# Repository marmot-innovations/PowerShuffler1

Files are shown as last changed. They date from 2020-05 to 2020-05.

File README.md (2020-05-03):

# PowerShuffler1
Summary: PowerShuffler1 is a HV isolated DC-DC charger PCBA for balancing weak cells within a large battery stack of Li-Ion cells.

Theory of operation: In a battery stack with 99 lithium-ion cells in series, there might be 1 or 2 weak cells that limit the usability of the entire battery pack. Let's assume the 99 li-ion cells are arranged in groups of 9 and there are certain groups that contain cells which are stronger than others. PowerShuffler1 is a PCBA that will piggy-back on top of the existing BMS that comes with the battery pack and draw power from the stronger group in order to charge up the 1 weak cell wherever it sits in the series of 99 cells. PowerShuffler1 has built-in intelligence not to over-discharge the stronger group by measuring the voltage of the 1 weak cell as it rises, and compares it to 1/9th of the stronger group's total voltage as it falls to within a certain threshold. Pre-programmed hysteresis prevents excessive start-stop charging as the cells are put through normal usage during the time when the existing BMS kicks in. Although intrusive, PowerShuffler1 is meant to be a diagnostics tool to verify and characterize weak cells within a battery stack on top of a pre-existing BMS. It does not replace the need for servicing the battery pack or using a better BMS down the road. PowerShuffler1 has no wired or wireless communication, which is not accessible anyway if piggy-backed within a battery pack enclosure.

Included in this project are:
1. Firmware for master MCU
2. Firmware for client MCU
3. PCB design for PCBA

Read the individual README for further details. Pictures will be added later to provide instructions for programming and installation, as well as board modifications where needed. Test data will be provided eventually.

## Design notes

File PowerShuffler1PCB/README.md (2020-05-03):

## PowerShuffler 1.0 PCB design schematic, layout, Gerbers, and BOM  
KiCAD 5.0.0 for PCB design  
Microsoft Excel web for BOM  
No 3D model  
No XY pick and place Centroid  
No ODB++  
No footprint library  
No schematic library

Design bugs and comments:  
1. S2 pins 3 and 4 are swapped. Use wire wrap to un-swap them.
2. F2 will drop about 0.1V under full 500mA load when charging. No way to measure OCV in this version. Manually take measurements and compensate by adjusting master MCU.
3. R12 cannot be switched off to stop charging. Everytime the client MCU is turned on to take a measurement it will move energy.
4. To program master MCU, remove R6 and C7 first, then replace them once programming is completed. These components will put too much load on ISP TPI programmer.
5. To program client MCU, remove C24 and (optionally) R22 first, then replace them once completed. These components will put too much load on ISP TPI programmer.
6. J2 and J4 do not need soldered headers for programming. Just shove a 5-pin 0.1" straight strip header into it to establish electrical contact. Look up "sneaky footprints PCB" on the web.
7. Mounting holes are for 4-40 screws and stand-offs.
8. Peak 75% efficiency during max charge rate as measured.
9. Less than 0.5mA current draw from input when idle, not charging.

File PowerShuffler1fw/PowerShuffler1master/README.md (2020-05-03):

## PowerShuffler Master Firmware  
Microchip (Atmel) ATTINY10 8MHZ  
Operational VCC 3.3V  
Programming VCC 5.0V  
Reset line voltage 12V  
TPI programming interface  
Programmer AVR ISP mk2

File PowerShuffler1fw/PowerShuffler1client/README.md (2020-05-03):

## PowerShuffler Client Firmware  
Microchip (Atmel) ATTINY10 8MHZ  
Operational VCC 3.3V  
Programming VCC 5.0V  
Normal reset line voltage (no need for 12V)  
TPI programming interface  
Programmer AVR ISP mk2

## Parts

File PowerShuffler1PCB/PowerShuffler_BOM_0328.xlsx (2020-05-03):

ref | QTY | value5 | footprint | Manuf P/N | Digikey P/N | description
U2, U6 | 2 | SWITCHDCDCLOPOW | BMB:10-μMAX_3x3mm | MAX17550AUB+ | MAX17550AUB+-ND | IC REG BUCK ADJ 25MA 10UMAX
C26, C27 | 2 | 15u | BMB:2917 | TR3E156M050C0300‎ | 718-1785-1-ND‎ | CAP TANT 15UF 20% 50V 2917
J3 | 1 | Conn_01x02 | BMB:Molex_Microfit3_Header_2pin_Angled_43650 | 0436500200‎ | WM1860-ND | CONN HEADER R/A 2POS 3MM
J1 | 1 | Conn_01x03 | BMB:Molex_Microfit3_Header_3pin_Angled_43650 | 0436500301‎ | ‎WM1866-ND‎ | CONN HEADER R/A 3POS 3MM
U4 | 1 | ISOLATEDDCDC | BMB:NSD05-S_6-DIP_1x1.6inch | NSD05-48S5‎ | 1866-3621-ND‎ | DC DC CONVERTER 5V 5W isolated
L1, L2 | 2 | 680u | BMB:SMD_Inductor_Shielded_6x6mm | VLS6045EX-681M | ‎445-180928-1-ND | FIX IND 680UH 320MA 2.95OHM SMD
S1 | 1 | SSR4 | BMB:SMD4_SSR_CPC1002N | CPC1002NTR‎ | CLA230CT-ND | SSR RELAY SPST-NO 700MA 0-60V
S2 | 1 | OPTOSOLO | BMB:SMD4_TL241AF-SSR_0.1_12x5mm | ‎LTV-816S | ‎160-1361-5-ND | OPTOISOLATR 5KV TRANSISTOR 4-SMD
J2 | 1 | Conn_01x05 | BMB:Staggered_ICSP_5x2.54mm_Straight |  |  | DO NOT POPULATE
J4 | 1 | Conn_01x05 | BMB:Staggered_ICSP_5x2.54mm_Straight |  |  | DO NOT POPULATE
C12, C14, C16, C19, C2, C28, C6, C9 | 8 | 0.1u | Capacitors_SMD:C_1206 | CL31B104KCFNNNE‎ | 1276-1151-1-ND | CAP CER 0.1UF 100V X7R 1206
C10, C22 | 2 | 0.22u | Capacitors_SMD:C_1206 | CL31B224KBFNNNE‎ | 1276-1106-1-ND
C20, C25, C4 | 3 | 10u | Capacitors_SMD:C_1206 | CL31B106KBHNNNE‎ | 1276-6767-1-ND | CAP CER 10UF 50V X7R 1206
C1, C11, C13, C15, C18, C21, C24, C3, C5, C7, C8 | 11 | 1u | Capacitors_SMD:C_1206 | CL31B105KBHNNNE‎ | ‎1276-1068-1-ND‎ | CAP CER 1UF 50V X7R 1206
C17, C23 | 2 | 4.7u | Capacitors_SMD:C_1206 | CL31B475KAHNNWE‎ | ‎1276-3178-1-ND
F1 | 1 | Fuse | Fuse_Holders_and_Fuses:Fuse_SMD1206_HandSoldering | C1F 3 | 507-1883-1-ND | FUSE 3.0A 125VAC FAST 1206
F2 | 1 | Fuse | Fuse_Holders_and_Fuses:Fuse_SMD1206_HandSoldering | C1F 1.5 | 507-1880-1-ND | FUSE 1.5A 125VAC FAST 1206
D1 | 1 | LED | LEDs:LED_1206 | 150120GS75000‎ | ‎732-4990-1-ND‎ | LED GREEN CLEAR 1206 SMD
D2, D3 | 2 | LED | LEDs:LED_1206 | 150120RS75000‎ | ‎732-4991-1-ND | LED RED CLEAR 1206 SMD
R20, R9 | 2 | 22.1 | Resistors_SMD:R_1206 | RMCF1206FT22R1‎ | ‎RMCF1206FT22R1CT-ND‎
R14, R17, R19, R6, R7, R8 | 6 | 390 | Resistors_SMD:R_1206 | RMCF1206JT390R‎ | ‎RMCF1206JT390RCT-ND‎
~~R18~~ | ~~1~~ | ~~470~~ | ~~Resistors_SMD:R_1206~~ | ~~RMCF1206JT470R‎~~ | ~~‎RMCF1206JT470RCT-ND‎~~
R3 | 1 | 210k | Resistors_SMD:R_1206 | ERA-8AEB2103V | P210KBCCT-ND | RES SMD 210K OHM 0.1% 1/4W 1206
R16, R5 | 2 | 158k | Resistors_SMD:R_1206 | RMCF1206FT158K‎ | ‎RMCF1206FT158KCT-ND‎ | RES 158K OHM 1% 1/4W 1206
R22 | 1 | 18.7k | Resistors_SMD:R_1206 | ‎ERA-8AEB1872V‎ | ‎P18.7KBCCT-ND‎ | RES SMD 18.7K OHM 0.1% 1/4W 1206
R4 | 1 | 19.1k | Resistors_SMD:R_1206 | ‎RT1206BRD0719K1L | YAG2018CT-ND‎ | RES SMD 19.1K OHM 0.1% 1/4W 1206
R1, R10, R13, R21 | 4 | 191k | Resistors_SMD:R_1206 | MCR18ERTF1913‎ | ‎RHM191KCJCT-ND‎ | RES SMD 191K OHM 1% 1/4W 1206
R11, R12, R18 | 3 | 2k | Resistors_SMD:R_1206 | RMCF1206FG2K00‎ | ‎RMCF1206FG2K00CT-ND‎ | RES 2K OHM 1% 1/4W 1206
R15, R2 | 2 | 49.9k | Resistors_SMD:R_1206 | RMCF1206FT49K9‎ | ‎RMCF1206FT49K9CT-ND‎ | RES 49.9K OHM 1% 1/4W 1206
R23 | 1 | 56.2k | Resistors_SMD:R_1206 | RT1206BRD0756K2L‎ | YAG2060CT-ND | RES SMD 56.2K OHM 0.1% 1/4W 1206
U1, U8 | 2 | MCP6401 | TO_SOT_Packages_SMD:SOT-23-5_HandSoldering | ‎MCP6401T-H/OT‎ | MCP6401T-H/OTCT-ND‎ | IC OPAMP GP 1 CIRCUIT SOT23-5 hi temp
U5 | 1 | MCP73831 | TO_SOT_Packages_SMD:SOT-23-5_HandSoldering | ‎MCP73831T-2DCI/OT‎ | ‎MCP73831T-2DCI/OTCT-ND‎ | IC CONTROLLR LI-ION 4.2V SOT23-5
U3, U7 | 2 | ATTINY | TO_SOT_Packages_SMD:SOT-23-6_Handsoldering | ‎ATTINY10-TSHR‎ | ‎ATTINY10-TSHRCT-ND‎ | IC MCU 8BIT 1KB FLASH SOT23

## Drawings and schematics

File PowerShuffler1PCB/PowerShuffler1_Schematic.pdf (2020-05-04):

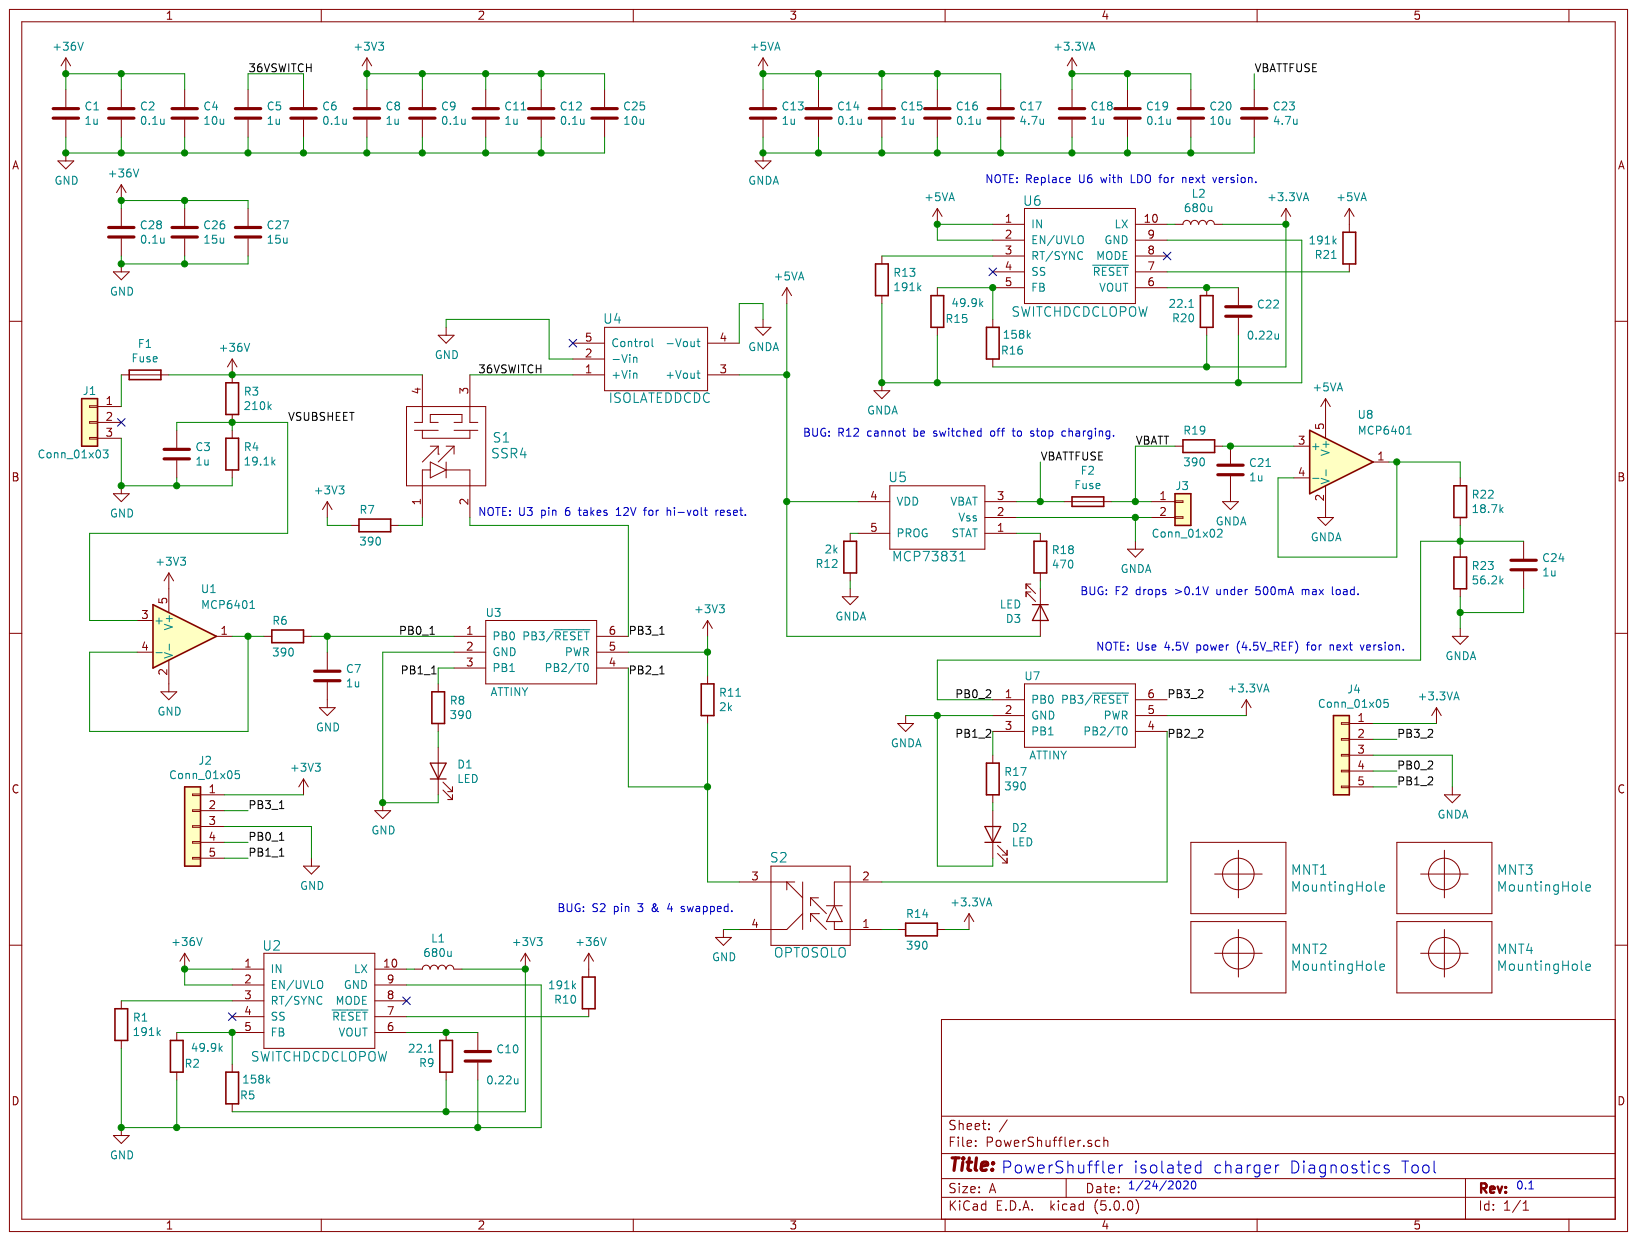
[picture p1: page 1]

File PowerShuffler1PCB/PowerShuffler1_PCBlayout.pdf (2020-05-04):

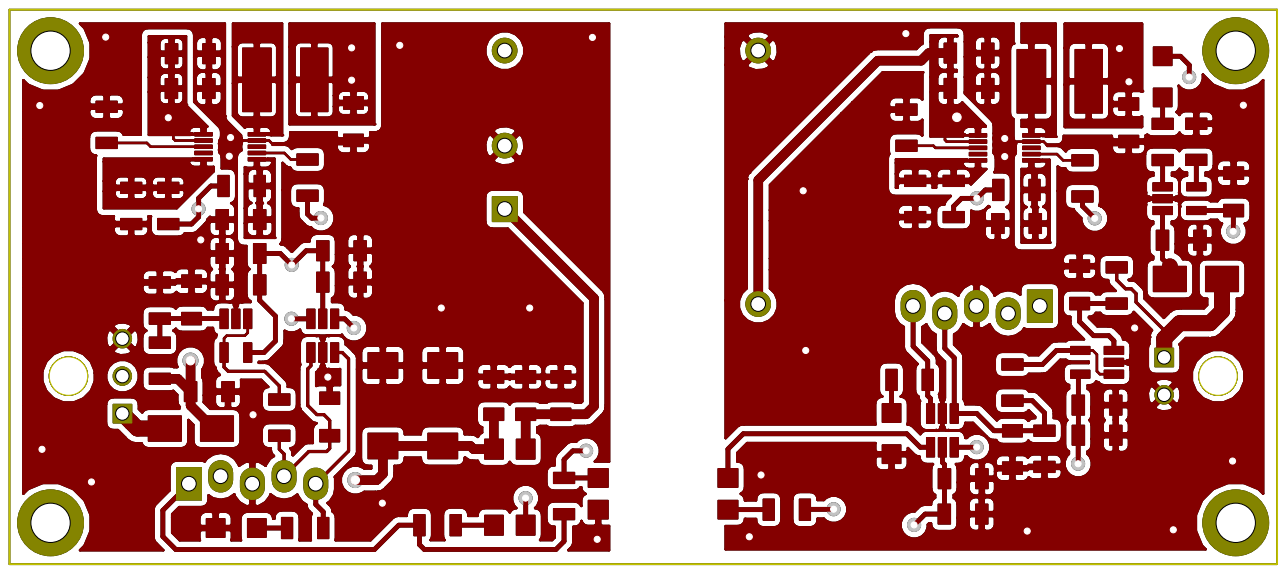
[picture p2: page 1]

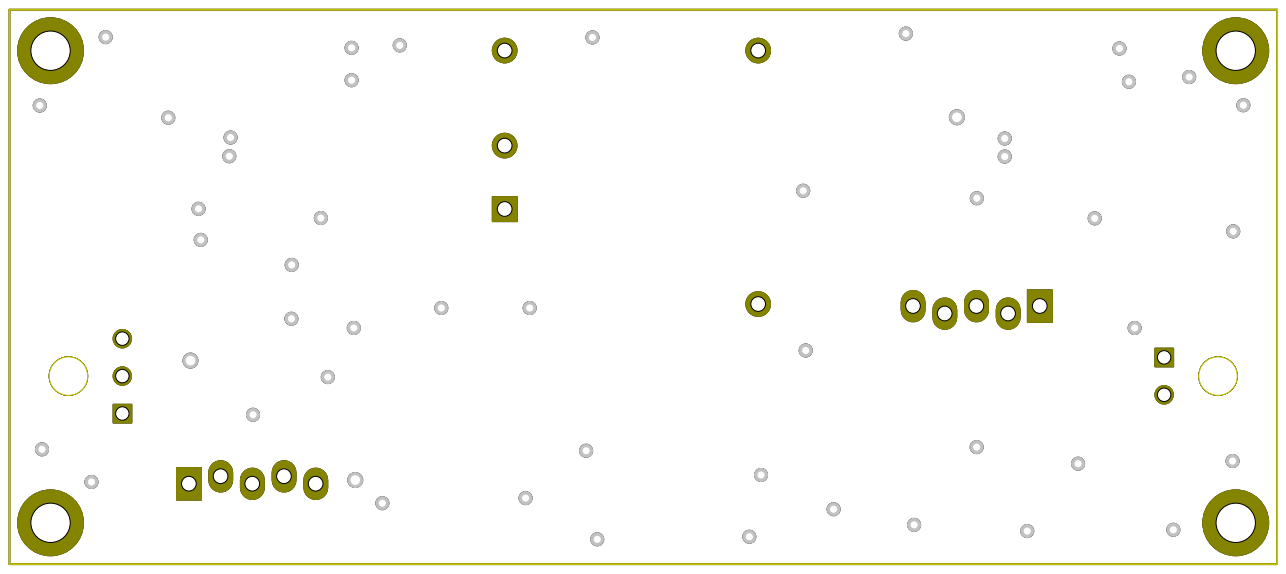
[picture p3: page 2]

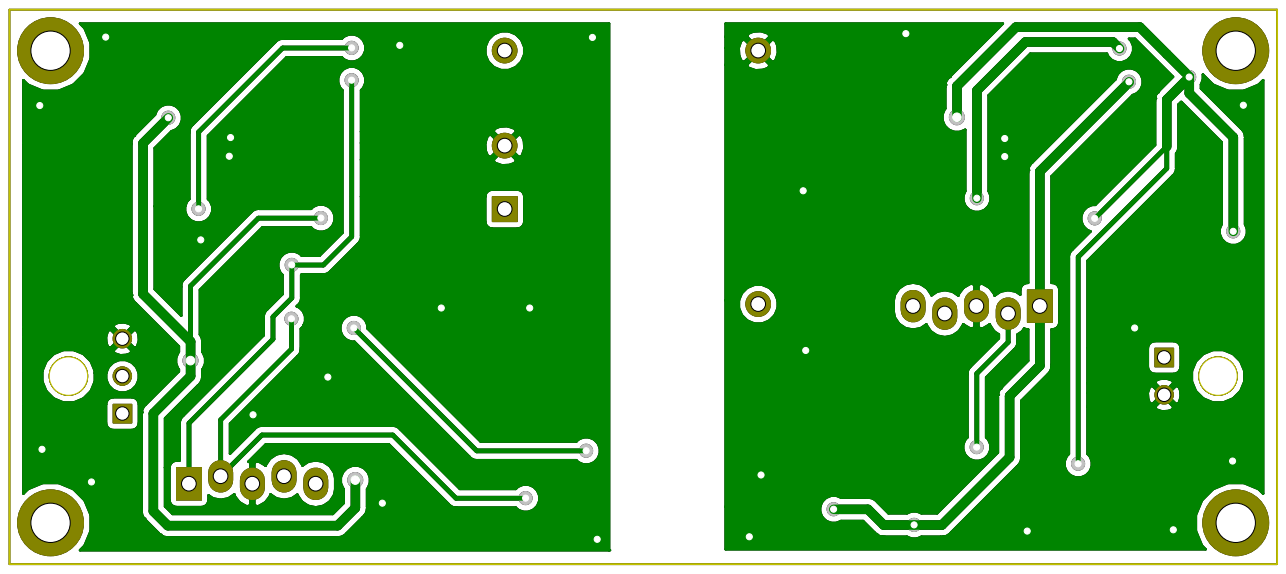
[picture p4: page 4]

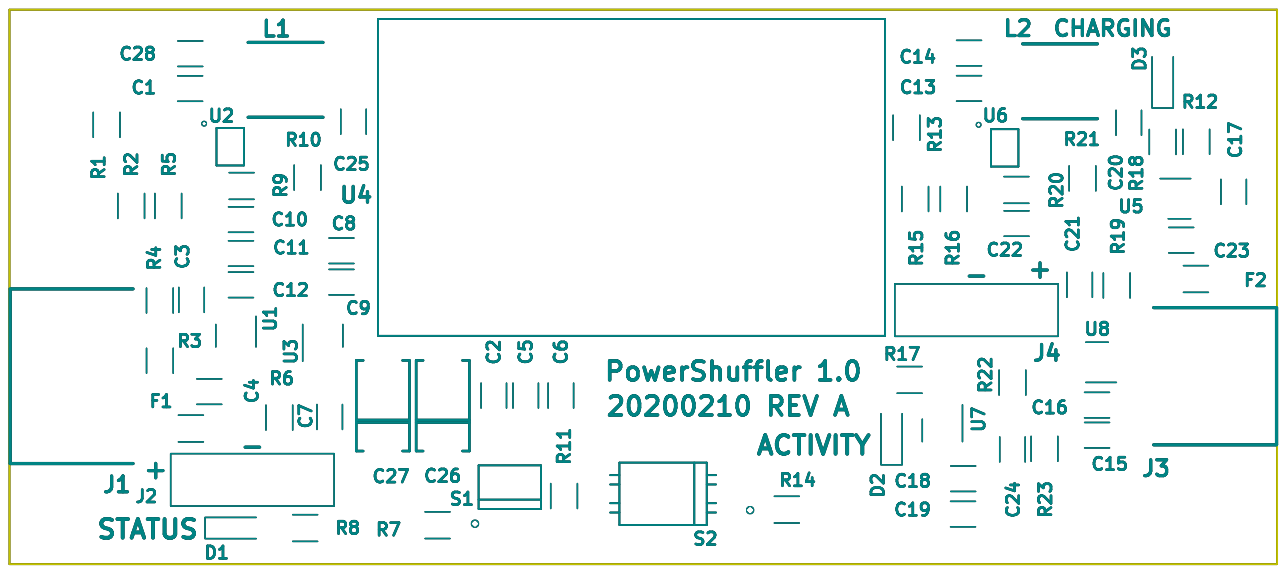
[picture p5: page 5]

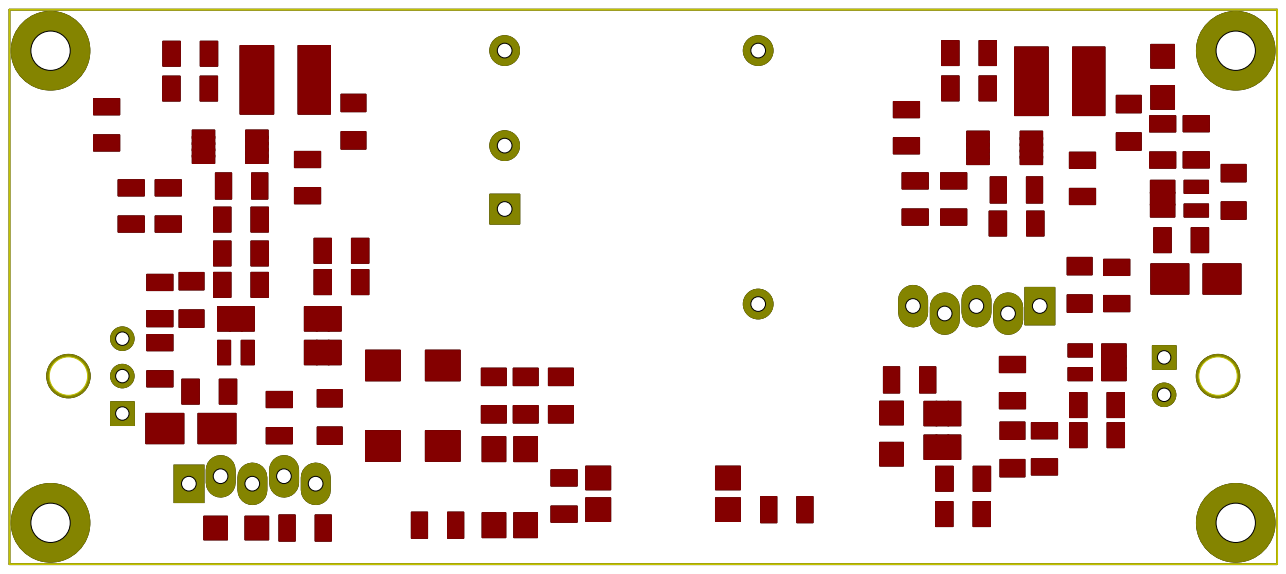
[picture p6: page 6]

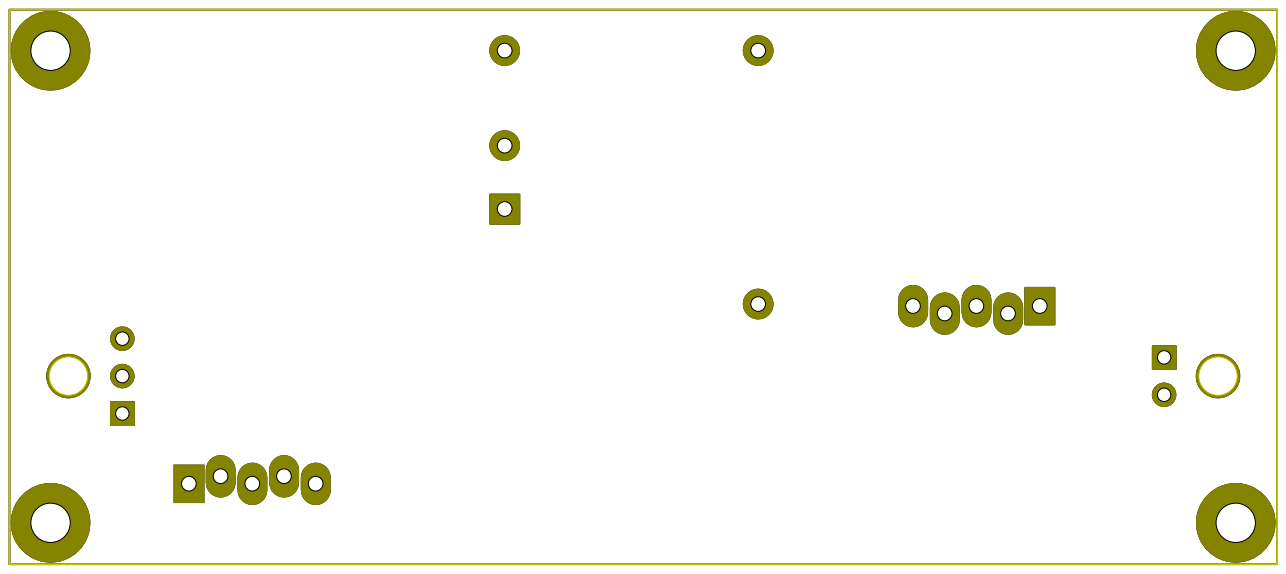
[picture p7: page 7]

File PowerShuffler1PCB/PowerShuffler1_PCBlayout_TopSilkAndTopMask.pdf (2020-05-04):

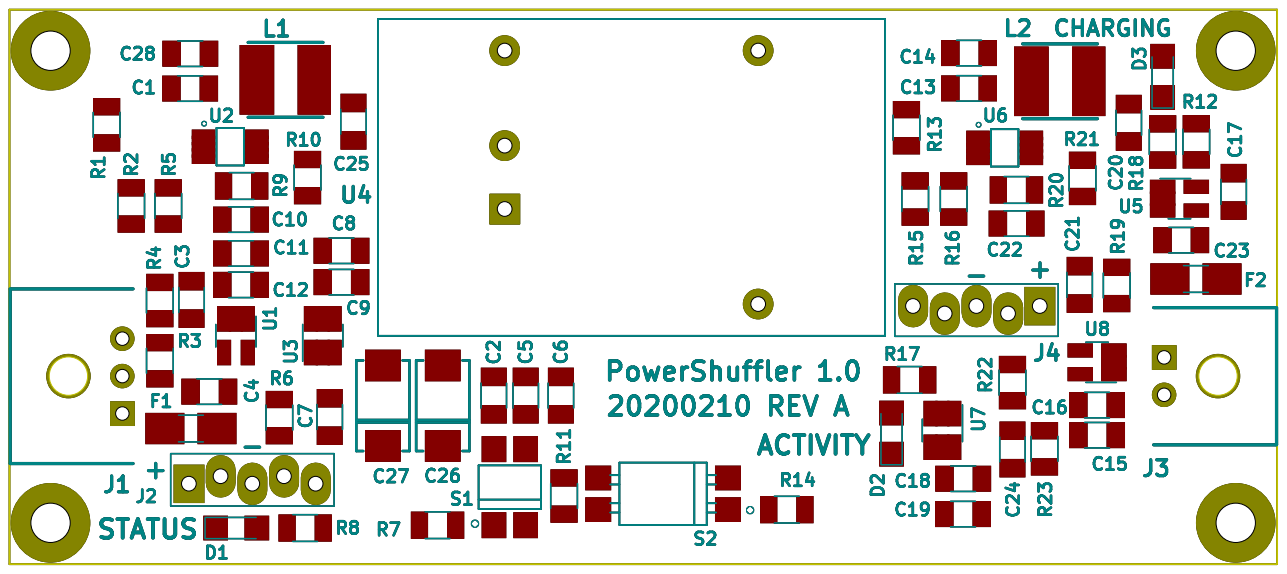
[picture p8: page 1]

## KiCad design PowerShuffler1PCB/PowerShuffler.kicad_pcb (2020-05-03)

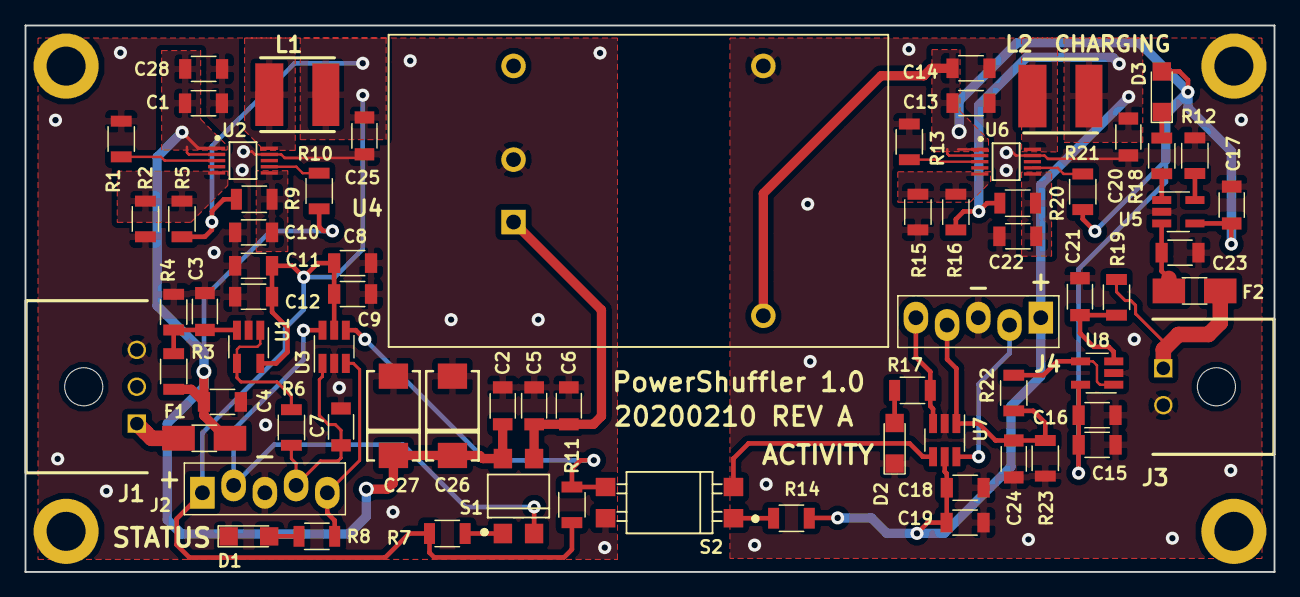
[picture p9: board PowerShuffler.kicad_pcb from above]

Board: 4 copper layers, 101.6 x 44.5 mm, 76 parts (0 on the bottom side), 39 nets.

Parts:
C1, C3, C5, C7, C8, C11, C13, C15, C18, C21, C24: 1u; C_1206
C2, C6, C9, C12, C14, C16, C19, C28: 0.1u; C_1206
C4, C20, C25: 10u; C_1206
C10, C22: 0.22u; C_1206
C17, C23: 4.7u; C_1206
C26, C27: 15u; 2917
D1, D2, D3: LED; LED_1206
F1, F2: Fuse; Fuse_SMD1206_HandSoldering
J1: Conn_01x03; Molex_Microfit3_Header_3pin_Angled_43650
J2, J4: Conn_01x05; Staggered_ICSP_5x2.54mm_Straight
J3: Conn_01x02; Molex_Microfit3_Header_2pin_Angled_43650
L1, L2: 680u; SMD_Inductor_Shielded_6x6mm
MNT1, MNT2, MNT3, MNT4: MountingHole; 3mm_hole
R1, R10, R13, R21: 191k; R_1206
R2, R15: 49.9k; R_1206
R3: 150k; R_1206
R4, R22: 18.7k; R_1206
R5, R16: 158k; R_1206
R6, R7, R8, R14, R17, R19: 390; R_1206
R9, R20: 22.1; R_1206
R11, R12: 2k; R_1206
R18: 470; R_1206
R23: 56.2k; R_1206
S1: SSR4; SMD4_SSR_CPC1002N
S2: OPTOSOLO; SMD4_TL241AF-SSR_0.1_12x5mm
U1, U8: MCP6401; SOT-23-5_HandSoldering
U2, U6: SWITCHDCDCLOPOW; 10-μMAX_3x3mm
U3, U7: ATTINY; SOT-23-6_Handsoldering
U4: ISOLATEDDCDC; NSD05-S_6-DIP_1x1.6inch
U5: MCP73831; SOT-23-5_HandSoldering

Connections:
+3.3VA: C18.1, C19.1, C20.1, J4.1, L2.2, R14.1, R16.1, R20.1, U7.5
+3V3: C8.1, C9.1, C11.1, C12.1, C25.1, J2.1, L1.2, R5.1, R7.2, R9.1, R11.1, U1.5, U3.5
+5VA: C13.1, C14.1, C15.1, C16.1, C17.1, D3.2, R21.2, U4.3, U5.4, U6.1, U6.2, U8.5
+36V: C1.1, C2.1, C4.1, C26.1, C27.1, C28.1, F1.1, R3.1, R10.2, S1.4, U2.1, U2.2
/36VSWITCH: C5.1, C6.1, S1.3, U4.1
/PB0_1: C7.1, J2.4, R6.1, U3.1
/PB0_2: C24.1, J4.4, R22.2, R23.1, U7.1
/PB1_1: J2.5, R8.1, U3.3
/PB1_2: J4.5, R17.1, U7.3
/PB2_1: R11.2, S2.3, U3.4
/PB2_2: S2.2, U7.4
/PB3_1: J2.2, S1.2, U3.6
/PB3_2: J4.2, U7.6
/VBATT: F2.1, J3.1, R19.2
/VBATTFUSE: C23.1, F2.2, U5.3
/VSUBSHEET: C3.1, R3.2, R4.1, U1.3
GND: C1.2, C2.2, C3.2, C4.2, C5.2, C6.2, C7.2, C8.2, C9.2, C10.2, C11.2, C12.2, C25.2, C26.2, C27.2, C28.2, D1.1, J1.3, J2.3, R1.2, R2.1, R4.2, S2.4, U1.2, U2.9, U3.2, U4.2
GNDA: C13.2, C14.2, C15.2, C16.2, C17.2, C18.2, C19.2, C20.2, C21.2, C22.2, C23.2, C24.2, D2.1, J3.2, J4.3, R12.1, R13.2, R15.1, R23.2, U4.4, U5.2, U6.9, U7.2, U8.2
unnamed: C10.1, R9.2, U2.6
unnamed: C21.1, R19.1, U8.3
unnamed: C22.1, R20.2, U6.6
unnamed: D1.2, R8.2
unnamed: D2.2, R17.2
unnamed: D3.1, R18.2
unnamed: F1.2, J1.1
unnamed: L1.1, U2.10
unnamed: L2.1, U6.10
unnamed: R1.1, U2.3
unnamed: R2.2, R5.2, U2.5
unnamed: R6.2, U1.1, U1.4
unnamed: R7.1, S1.1
unnamed: R10.1, U2.7
unnamed: R12.2, U5.5
unnamed: R13.1, U6.3
unnamed: R14.2, S2.1
unnamed: R15.2, R16.2, U6.5
unnamed: R18.1, U5.1
unnamed: R21.1, U6.7
unnamed: R22.1, U8.1, U8.4

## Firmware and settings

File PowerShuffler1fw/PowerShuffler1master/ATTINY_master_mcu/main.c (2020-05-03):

/*
 * This file is part of the PowerShuffler project.
 *
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
 * ATTINY_master_mcu::main.c
 *
 * Created: 3/16/2020 4:00:40 PM
 * Author : mike
 * Summary: This master MCU code as-is is designed to run on a 9S 4.2V Li-ion battery stack.
 *          Parameters can be adjusted to run on 2S - 11S battery stacks (electrically limited).
 */
#define F_CPU                 8000000UL // 8 MHz
#define VERIFYTRIGGERTIMEOUT  4      // Max timeout ticks to verify not a glitch
#define READINGTIMEOUT        15625  // Reading timeout tick 62,500 (or about .5s at 31.25khz)
#define MAXTIMEOUT            0xFFFF // Max timeout tick 65,535
#define MAXTIMEOUTCOUNT       5      // Max iterations of max timeout ticks
#define BRIEFBLINKDELAYCOUNT  0xFFFF // Number of cycles to delay between LED on-off
#define SLEEPDELAYCOUNT       30     // Number of cycles to sleep for LED heartbeat ~5min (measured 4min 56sec on a stopwatch)
#define ADCITERATIONS         4      // Number of readings to take an average. Base 2 number saves memory.
#define ADCTHRESHOLDHI        7      // Threshold ADC value for stopping the client MCU / charging (battery delta of 0.124V)
#define ADCTHRESHOLDLOW       4      // Hysteresis threshold of restarting client MCU / charging (battery delta of 0.071V)
#define MAXVOLTAGEADCVALUE    232    // ADC value of maximum output battery voltage (about 4.12V)
#define MINVOLTAGEADCVALUE    163    // ADC value of minimum input battery voltage (about 2.90V)
#define BLINKTOGGLEVALUE      16384  // Toggle LED when count reaches this value. Base 2 number saves memory.
#define CLIENTDEBOUNCEDELAY   0xFFFF // Number of cycles for client MCU power-on debounce delay and restarting main loop
#define POWERDEBOUNCEDELAYMS  3000   // Power-on debounce delay, which should be <8 seconds (watchdog)
#define ADCREADDELAYMS        10     // Delay between ADC readings

#include <avr/io.h>
#include <avr/interrupt.h>
#include <avr/sleep.h>
#include <avr/wdt.h>
#include <util/delay.h> // _delay_ms

enum ReadDataState
{
	Read_Idle = 0,
	Read_VerifyTrigger,
	Read_Reading,
	Read_Timeout,
	Read_Error
};

enum ReadDataState g_readDataState = Read_Idle;
unsigned int g_incomingCount = 0;      // 0 is error (i.e. INT0 held lo by client MCU to indicate an error).
unsigned int g_ledBlinkCount = 0;      // counter to randomly toggle the LED each time it hits BLINKTOGGLEVALUE.
unsigned int g_adcThreshold = 0;       // Variable threshold to implement hysteresis
unsigned short g_idleTimeoutCount = 0; // counter to activate idle timeout

void initializeRegisters()
{
	g_adcThreshold = ADCTHRESHOLDHI;

	// Clock frequency
	CCP    = 0xD8; // write the signature to enable CPU changes per datasheet
	CLKPSR = 0x00; // 0000 0000 for prescaler 1

	// Watchdog timer and Sleep Mode
	WDTCSR = 0x61; // 0110 0001 Interrupt Mode and 1024k prescalar (about 8 seconds)
	SMCR   = 0x05; // 0000 0101 Power-Down mode

	// Ports and pins
	// PB0 = ADC0 input battery voltage
	// PB1 = LED output, hi on, lo off (default lo)
	// PB2 = data input, hi idle (default hi)
	// PB3 = client MCU switch, hi off (default hi), lo on, 12V high-voltage reset
	PUEB |= _BV(3); // Enable pull-up resistor to fully float PB3 hi
	DDRB |= _BV(1); // 0000 0010 for STATUS LED output pin PB1

	_delay_ms(POWERDEBOUNCEDELAYMS); // Power-on debounce delay to wait for steady-state
	wdt_reset();

	// Timers
	OCR0A  = MAXTIMEOUT;
	// TCCR0A = 0X00; // 0000 0000 wgm01=0, wgm00=0
	// TCCR0B = 0x00; // 0000 0000 wgm03=0, wgm02=0, disable timer, no clock source

	// ADC
	ADCSRA = 0x83; // 1000 0011 enables ADC and set prescaler 8
	// ADCSRB = 0x00; // Single Conversion Mode
	// ADMUX = 0x00; // Select ADC0 on PB0
	DIDR0 = 0x0E; // 0000 1110 disables buffers on unused ADC pins for power savings

	// Interrupts
	// EICRA  = 0x00; // 0000 0000 to initially enable interrupt on low INT0
	EIMSK  = 0x01; // 0000 0001 to enable INT0 interrupts
	TIMSK0 = 0x03; // 0000 0011 to enable interrupt on timer match OCF0A and TOV
	SREG   = 0x80; // 1000 0000 to globally enable interrupts
}

void resetAndStartTimer()
{
	TCNT0   = 0;    // reset timer count to 0
	TCCR0B |= 0x04; // start timer w/ prescaler 256
}

void stopTimer()
{
	TCCR0B &= 0xFB; // stop timer
}

void resetReadStateToIdle()
{
	g_idleTimeoutCount = 0;
	g_readDataState = Read_Idle;
	OCR0A = MAXTIMEOUT;
	EICRA = 0x00;  // reset to enable interrupt on low INT0
	EIMSK = 0x01;  // Enable INT0 interrupt
}

void toggleLed() // toggles LED on PB1
{
	PORTB = (PORTB & _BV(1)) ? PORTB & ~_BV(1) : PORTB | _BV(1);
}

void turnOnLed()
{
	PORTB |= _BV(1); // set PB1
}

void turnOffLed()
{
	PORTB &= ~_BV(1); // clear PB1
}

// make LED look like it's blinking when called from inside a busy-loop
void incrementAndBlinkLed()
{
	g_ledBlinkCount++; // start from 1 initially
	if(0 == (g_ledBlinkCount % BLINKTOGGLEVALUE))
		toggleLed();
}

void turnOnClient()
{
	PUEB &= ~_BV(3); // Disable pull-up resistor to save power
	DDRB |= _BV(3);  // DCDC enable output pin PB3
	for(unsigned int j=0; j<CLIENTDEBOUNCEDELAY; j++) // Wait for client power steady-state and delay restarting of main loop.
		incrementAndBlinkLed();
}

void turnOffClient()
{
	PUEB |= _BV(3);  // Enable pull-up resistor to fully float PB3 hi
	DDRB &= ~_BV(3); // Set PB3 to float hi to turn off client.
}

void startADC()
{
	ADCSRA |= 0x40; // 0100 0000 set ADSC to start single conversion mode
}

unsigned short adcInProgress()
{
	return ADCSRA & 0x40; // 0100 0000 returns 0 if adc is done, non-zero otherwise.
}

// 0   = 0.0V, which is battery 0.0V
// 255 = 3.394V, which is battery 4.530V after resistor divider
// Each step is 0.01331V, which is battery 0.01776V per step
unsigned short adcValue()
{
	return ADCL;
}

unsigned short getAdcValueBusyWait()
{
	startADC();
	while(adcInProgress()) // busy waits until ADC conversion is done
		incrementAndBlinkLed();

	return adcValue();
}

unsigned int getAdcValueBusyWaitWithAveraging()
{
	unsigned int adcvalue = 0;
	for(int i=0; i<ADCITERATIONS; i++)
	{
		if(i) _delay_ms(ADCREADDELAYMS); // Skip delaying the first reading, then delay in milliseconds
		adcvalue += (unsigned int)getAdcValueBusyWait();
	}

	return adcvalue / ADCITERATIONS; // average ADC value
}

unsigned short readPinB2()
{
	return PINB & _BV(2); // 0000 0100
}

//void busywaitDelay(unsigned int count) // Not enough memory to implement busy-wait delay and toggle LED subroutine
//{
	//while(count)
	//{
		//incrementAndBlinkLed();
		//count--;
	//}
//}

ISR(INT0_vect)
{
	// if triggering on low level, make sure not a glitch
	// then start timer for Reading, switch to trigger on falling edge and count edges
	// when the timer expires, reset to interrupt triggering on lo
	switch(g_readDataState)
	{
		case Read_Idle:
			stopTimer();
			EIMSK = 0x00; // Disable INT0 interrupt
			g_readDataState = Read_VerifyTrigger; // Set next state
			OCR0A = VERIFYTRIGGERTIMEOUT; // Set timeout
			resetAndStartTimer();
			break;
		case Read_Reading:
			g_incomingCount++;
			break;
		default: // Interrupt has been triggered out-of-state
			break;
	}
}

ISR(TIM0_COMPA_vect)
{
	switch(g_readDataState)
	{
		case Read_VerifyTrigger:
			stopTimer();
			if(readPinB2()) // if PB2 has floated hi, signal was a glitch, go back to Idle
			{
				resetReadStateToIdle();
			}
			else            // PB2 still held lo, not a glitch, continue Reading
			{
				g_incomingCount = 0; // set count to 0
				g_readDataState = Read_Reading;
				OCR0A = READINGTIMEOUT; // Set reading timeout value
				EICRA = 0x02; // 0000 0010 enable interrupt on falling edge of INT0
				EIMSK = 0x01; // Enable INT0 interrupt
			}
			resetAndStartTimer();
			break;
		case Read_Reading:
			stopTimer();
			g_readDataState = readPinB2() ? Read_Timeout : Read_Error; // Error if PB2 held lo after timeout
			EIMSK = 0x00; // Disable INT0 interrupt
			break;
		default:
			break;
	}
}

ISR(TIM0_OVF_vect)
{
	wdt_reset();
	if(g_readDataState == Read_Idle && ++g_idleTimeoutCount > MAXTIMEOUTCOUNT)
	{
		stopTimer();
		g_readDataState = Read_Error; // Timeout error
		g_idleTimeoutCount = 0; // clear idle timeout count before continuing
		EIMSK = 0x00; // Disable INT0 interrupt
	}
}

ISR(WDT_vect)
{
	// do nothing and wake up MCU
}

// LED status behavior and description:
//   - Rapid blinking                                 = activity (reading data and/or charging)
//   - Short series of blinks, then off w/heartbeat   = no charging
//   - Two short blinks per sleep time, then off w/hb = input voltage below threshold, conserving power
//   - Solid on w/ inverted hb                        = Error
//   - Off at all times                               = no power
int main(void)
{
	initializeRegisters();

    while (1)
    {
		if(getAdcValueBusyWait() > MINVOLTAGEADCVALUE) // Turn on client MCU if input voltage is above minimum voltage. Otherwise, save power.
		{
			turnOnClient();         // Turn on client MCU
			resetReadStateToIdle(); // Starts listening for input
			resetAndStartTimer();   // Starts timer
			while(g_readDataState != Read_Timeout && g_readDataState != Read_Error) // Busy waits until error or until reading is done
				incrementAndBlinkLed();

			if(g_readDataState == Read_Timeout)
			{
				// Re-acquire ADC reading since there might have been a delay, then determine if charging needs to continue or stop
				if(g_incomingCount < (getAdcValueBusyWaitWithAveraging()+g_adcThreshold) // keep charging if output is lower than input voltage threshold
					&& g_incomingCount < MAXVOLTAGEADCVALUE) // stop charging if output voltage hits an absolute max
				{
					g_adcThreshold = ADCTHRESHOLDHI; // Boost the output voltage to higher threshold
					continue; // skips the rest of the while-loop and start over
				}
				g_adcThreshold = ADCTHRESHOLDLOW; // Reset to a lower voltage threshold for hysteresis
				turnOffLed(); // keep LED off to indicate OK
			}
			else // Error
			{
				turnOnLed(); // keep LED solid on to indicate error
			}
		}
		else
		{
			turnOffLed(); // turn off LED to save power
			for(unsigned short i=0; i<4; i++) // Double-blink LED
			{
				for(unsigned int j=0; j<BRIEFBLINKDELAYCOUNT; j++); // Not enough memory to use _delay_ms
				toggleLed();
			}
		}
		turnOffClient();
		ADCSRA &= 0x7F; // disable ADC
		PRR = 0x03; // turn off ADC and timers to save power

		for(unsigned short i=0; i<SLEEPDELAYCOUNT; i++) // Sleep before starting again. Blip LED for heartbeat.
		{
			wdt_reset();
			sleep_mode();
			toggleLed();
			for(unsigned int j=0; j<BRIEFBLINKDELAYCOUNT; j++); // Not enough memory to use _delay_ms
			toggleLed();
		}

		PRR = 0x00; // restore power
		ADCSRA |= 0x80; // enable ADC
	}
}

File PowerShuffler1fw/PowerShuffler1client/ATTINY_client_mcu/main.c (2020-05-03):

/*
 * This file is part of the PowerShuffler project.
 *
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
 * ATTINY_client_mcu::main.c
 *
 * Created: 3/23/2020 2:09:01 PM
 * Author : mike
 * Summary: This client MCU code as-is is designed to run on any 4.2V single cell Li-ion battery.
 *          Parameters can be adjusted as needed for your application.
 */
#define F_CPU 8000000UL // 8 MHz
#define TRIGGERTIMEOUTCOUNT  256   // minimum iterations to trigger master MCU reading
#define TRANSMITDELAYCOUNT   128   // number of iterations between transmitting edges (1 bit = 1 falling and 1 rising edge)
#define POWERDEBOUNCEDELAYMS 1000  // power-on debounce delay must be less than 4 seconds due to watchdog timeout
#define ADCITERATIONS        3     // Number of readings to take an average
#define ADCREADDELAYMS       10    // Delay between ADC readings
#define BRIEFBLINKDELAYMS    50    // Duration of short LED blink
#define MAXVOLTAGEADCVALUE   237   // ADC value of maximum battery voltage (about 4.20V battery)
#define BLINKTOGGLEVALUE     16384 // Toggle LED when count reaches this value

#include <avr/io.h>
#include <util/delay.h>
#include <avr/interrupt.h>
#include <avr/sleep.h>
#include <avr/wdt.h>

unsigned int g_ledBlinkCount = 0; // counter to randomly toggle the LED each time it hits BLINKTOGGLEVALUE.

void initializeRegisters()
{
	// Clock frequency
	CCP    = 0xD8; // write the signature to enable CPU changes per datasheet
	CLKPSR = 0x00; // 0000 0000 for prescaler 1

	// Watchdog timer and Sleep Mode
	WDTCSR = 0x60; // 0110 0000 Interrupt Mode and 512k prescalar (about 4 seconds)
	SMCR   = 0x05; // 0000 0101 Power-Down mode

	_delay_ms(POWERDEBOUNCEDELAYMS); // power-on debounce. Roughly the amount of time needed for Li-ion charger to turn on and reach steady-state.
	wdt_reset();

	// Ports and pins
	// PB0 = ADC0 output battery voltage
	// PB1 = LED output, hi on, lo off (default lo)
	// PB2 = data output, hi idle (default hi)
	// PB3 = /reset (not used for anything else)
	// PUEB  |= _BV(0); // for debugging, enable pull-up on ADC0
	PUEB  |= _BV(3); // enable pull-up on input PB3 (noise reduction for floating pin)
	PORTB |= _BV(2); // ensure output PB2 is hi (not transmitting / idle)
	DDRB  |= _BV(1); // 0000 0010 for STATUS LED output pin PB1
	DDRB  |= _BV(2); // 0000 0100 for data output pin PB2

	// ADC
	ADCSRA = 0x83; // 1000 0011 enables ADC and set prescaler 8
	// ADCSRB = 0x00; // Single Conversion Mode
	// ADMUX = 0x00; // Select ADC0 on PB0
	DIDR0 = 0x0E; // 0000 1110 disables buffers on unused ADC pins for power savings

	// Interrupts
	SREG = 0x80; // 1000 0000 to globally enable interrupts
}

void toggleLed() // toggles LED on PB1
{
	PORTB = (PORTB & _BV(1)) ? PORTB & ~_BV(1) : PORTB | _BV(1);
}

void turnOnLed()
{
	PORTB |= _BV(1); // 0000 0010 set PB1
}

void turnOffLed()
{
	PORTB &= ~_BV(1); // 1111 1101 clear PB1
}

void incrementAndBlinkLed()
{
	if(!(++g_ledBlinkCount % BLINKTOGGLEVALUE)) // make LED look like it's blinking inside a loop
		toggleLed();
}

void startADC()
{
	ADCSRA |= 0x40; // 0100 0000 set ADSC to start single conversion mode
}

unsigned short adcInProgress()
{
	return ADCSRA & 0x40; // 0100 0000 returns 0 if adc is done, non-zero otherwise.
}

unsigned short adcValue()
{
	// 0   = 0.0V, which is battery 0.0V
	// 255 = 3.406V, which is battery 4.519V after resistor divider
	// Each step is 0.01335V, which is battery 0.01775V per step
	return (unsigned short)ADCL;
}

unsigned short getAdcValueBusyWait()
{
	startADC();
	while(adcInProgress()) // busy waits until ADC conversion is done
	{
		incrementAndBlinkLed();
	}
	return adcValue();
}

void transmitOneTick()
{
	PORTB &= ~_BV(2);
	for(unsigned int i=0; i<TRANSMITDELAYCOUNT; i++)
		incrementAndBlinkLed();
	PORTB |= _BV(2);
	for(unsigned int i=0; i<TRANSMITDELAYCOUNT; i++)
		incrementAndBlinkLed();
}

void triggerRead()
{
	PORTB &= ~_BV(2);
	for(unsigned int i=0; i<TRIGGERTIMEOUTCOUNT; i++) // hold lo for minimum trigger count
		incrementAndBlinkLed();
	PORTB |= _BV(2);
	for(unsigned int i=0; i<TRANSMITDELAYCOUNT; i++) // reset to hi for data output
		incrementAndBlinkLed();
}

void outputDataError() // holds the output lo for duration of power-on, solid LED
{
	PORTB &= ~_BV(2);
	turnOffLed();
	_delay_ms(BRIEFBLINKDELAYMS);
	turnOnLed();
}

void resetAndStart()
{
	wdt_reset();
	turnOffLed();
}

ISR(WDT_vect)
{
	// do nothing and wake up MCU
}

// LED status behavior and description:
//   - Rapid blinking = sending data
//   - Short series of blinks, then off = send data complete
//   - Solid on = Error
//   - Off at all times = Idle / off
int main(void)
{
	initializeRegisters();

    while (1)
    {
		resetAndStart();
		unsigned int adcvalue = 0;
		for(int i=0; i<ADCITERATIONS; i++)
		{
			if(i) _delay_ms(ADCREADDELAYMS); // skips delaying of the first reading
			adcvalue += (unsigned int)getAdcValueBusyWait();
		}
		adcvalue /= ADCITERATIONS; // average ADC value

		if(adcvalue > MAXVOLTAGEADCVALUE || adcvalue == 0) // Over-voltage or grounded ADC input
		{
			 outputDataError(); // Error
		}
		else
		{
			triggerRead(); // trigger the master MCU to start reading
			for(int i=0; i<adcvalue; i++)
			{
				transmitOneTick(); // transmit 1 bit at a time
			}
			turnOnLed();
			_delay_ms(BRIEFBLINKDELAYMS);
			turnOffLed(); // No errors
		}

		ADCSRA &= 0x7F; // disable ADC
		PRR = 0x03; // turn off ADC and timers to save power
		wdt_reset();
		sleep_mode();
		PRR = 0x00; // restore power
		ADCSRA |= 0x80; // enable ADC
    }
}

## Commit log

2020-05-03 Create README for PowerShuffler1 PCB
2020-05-03 Add PCB design files, KiCAD and BOM
    [PowerShuffler.kicad_pcb, PowerShuffler.sch, PowerShuffler_BOM_0328.xlsx]
2020-05-03 Create README for gerbers
2020-05-03 Add PCB design files, gerbers
    [PowerShuffler-B.Cu.gbl, PowerShuffler-B.Mask.gbs, PowerShuffler-Edge.Cuts.gm1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]
2020-05-04 Add PCB design drawings and schematic PDF

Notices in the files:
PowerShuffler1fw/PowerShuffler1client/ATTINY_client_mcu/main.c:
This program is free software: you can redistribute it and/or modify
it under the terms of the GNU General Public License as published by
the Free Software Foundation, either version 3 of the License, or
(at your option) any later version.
